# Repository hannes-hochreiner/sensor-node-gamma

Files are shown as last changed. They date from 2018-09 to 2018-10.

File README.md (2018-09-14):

# Sensor Node Gamma

## Core parts

### MCU
  * manufacturer: STMicroelectronics
  * manufacturer id: STM32L021K4T6
  * digi-key id: [497-17903-ND](https://www.digikey.de/product-detail/de/stmicroelectronics/STM32L021K4T6/497-17903-ND)
  * [datasheet](http://www.st.com/content/ccc/resource/technical/document/datasheet/86/a6/5f/95/33/50/4e/d6/DM00206858.pdf/files/DM00206858.pdf/jcr:content/translations/en.DM0020685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)
  * sleep current: 0.54 µA
  * price: 1.87 EUR

### transmitter
  * manufacturer: Silicon Labs
  * manufacturer id: SI4012-C1001GTR
  * digi-key id: [336-4153-1-ND](https://www.digikey.de/product-detail/de/silicon-labs/SI4012-C1001GTR/336-4153-1-ND/7650432)
  * [datasheet](http://www.silabs.com/documents/public/data-sheets/Si4012.pdf)
  * sleep current: 0.01 µA
  * price: 0.89 EUR

### sensor
  * manufacturer: Sensirion AG
  * manufacturer id: SHTC3
  * digi-key id: [1649-1105-1-ND](https://www.digikey.de/product-detail/de/sensirion-ag/SHTC3/1649-1105-1-ND/9477852)
  * [datasheet](https://media.digikey.com/pdf/Data%20Sheets/Sensirion%20PDFs/SHTC3_Prelim.pdf)
  * sleep current: 0.3 µA
  * price: 3.67 EUR

### antenna
  * manufacturer: Linx Technologies Inc.
  * manufacturer id: ANT-433-SP
  * digi-key id: [ANT-433-SP-ND](https://www.digikey.de/product-detail/de/linx-technologies-inc/ANT-433-SP/ANT-433-SP-ND/1679578)
  * [datasheet](https://linxtechnologies.com/wp/wp-content/uploads/ant-433-sp.pdf)
  * price: 2.07 EUR

## Power consumption

### Sleep

about 0.85 µA

CR2032: about 230 mAh

about 30 y of sleep

## Price

  * PCB: 7.50 EUR

price of the main components: 16 EUR

## Effort
  * system design: 1.5 h
  * circuit design: 2.5 h
  * pcb layout: 5.25 h
  * checks: 1.25 h

## TODOs
  * check all custom components and footprints

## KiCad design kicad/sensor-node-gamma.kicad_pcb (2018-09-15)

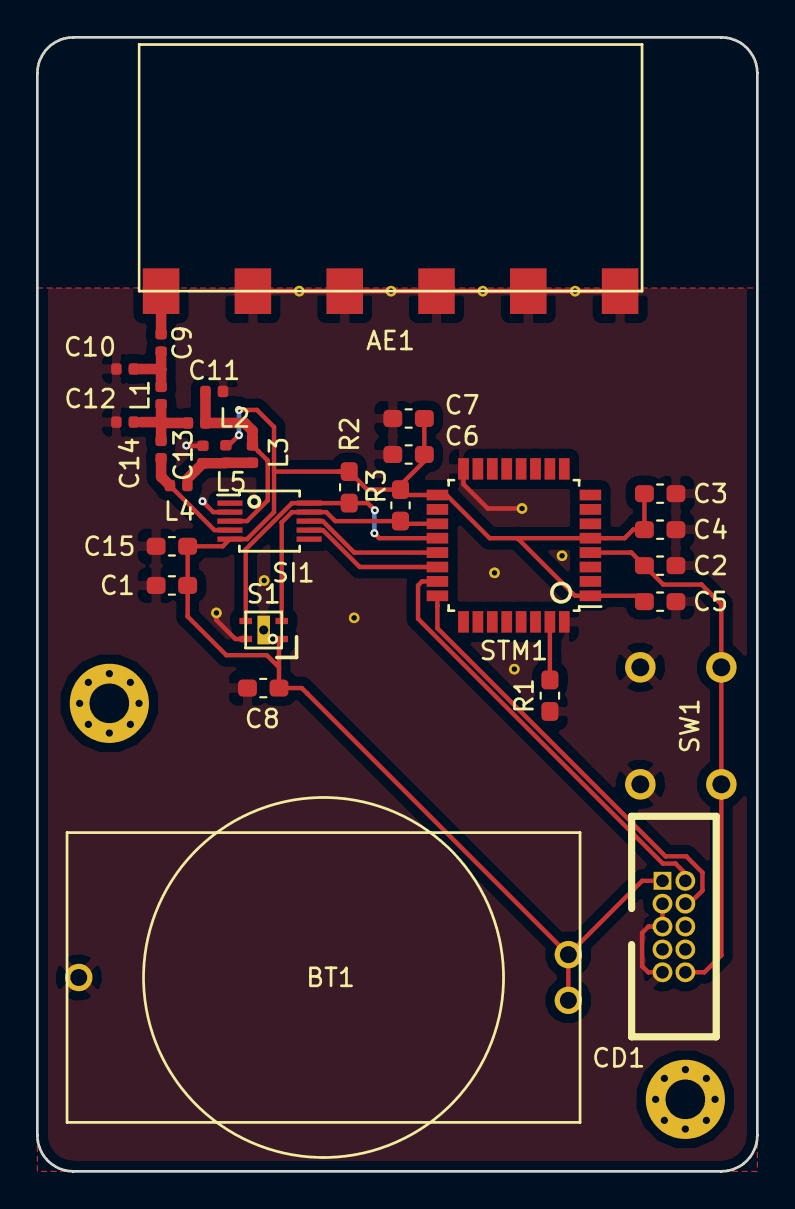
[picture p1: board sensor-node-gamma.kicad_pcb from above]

Board: 2 copper layers, 40.0 x 63.0 mm, 41 parts (0 on the bottom side), 16 nets.

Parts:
AE1: Antenna_Chip; ANT-433-SP
BT1: Custom_Battery; HU2032-LF
C1, C3: 1µF; C_0603_1608Metric_Pad1.05x0.95mm_HandSolder
C2, C4, C5, C6, C8, C15: 0.1µF; C_0603_1608Metric_Pad1.05x0.95mm_HandSolder
C7: 10µF; C_0603_1608Metric_Pad1.05x0.95mm_HandSolder
C9: 270pF; C_0402_1005Metric
C10, C12: 6.8pF; C_0402_1005Metric
C11: 4.3pF; C_0402_1005Metric
C13: 2.7pF; C_0402_1005Metric
C14: 1.8pF; C_0402_1005Metric
CD1: CORTEX-DEBUG
L1: 18nH; L_0402_1005Metric
L2: 56nH; L_0402_1005Metric
L3, L4: 16nH; L_0402_1005Metric
L5: 220nH; L_0402_1005Metric
R1, R2, R3: 10k; R_0603_1608Metric_Pad1.05x0.95mm_HandSolder
Ref**: Val**; STICH
Ref**#2, Ref**#3, Ref**#4, Ref**#5, Ref**#6, Ref**#7, Ref**#8, Ref**#9, Ref**#10, Ref**#11: Val**; STICH
S1: SHTC3
SI1: SI4012; MSOP-10_3x3mm_P0.5mm
STM1: STM32L021K4T6; LQFP-32_7x7mm_P0.8mm
SW1: SW_Push; switch

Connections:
/3V3: BT1.1, C1.2, C3.1, C4.1, C5.2, C6.1, C7.1, C8.1, C15.2, CD1.1, L5.1, R2.1, R3.2, S1.1, SI1.5, STM1.1, STM1.5, STM1.17
/I2C_SCL: R3.1, S1.2, SI1.9, STM1.19
/I2C_SDA: R2.2, S1.3, SI1.10, STM1.20
/RFM_ENABLE: SI1.8, STM1.21
/SWD_CLK: CD1.4, STM1.24
/SWD_IO: CD1.2, STM1.23
/~RFM_IRQ: SI1.7, STM1.22
/~SWD_RST: C2.1, CD1.10, STM1.4, SW1.2
GND: AE1.2, BT1.2, C1.1, C2.2, C3.2, C4.2, C5.1, C6.2, C7.2, C8.2, C10.1, C11.2, C12.1, C13.1, C15.1, CD1.3, CD1.5, CD1.9, R1.1, Ref**.1, Ref**#2.1, Ref**#3.1, Ref**#4.1, Ref**#5.1, Ref**#6.1, Ref**#7.1, Ref**#8.1, Ref**#9.1, Ref**#10.1, Ref**#11.1, S1.4, SI1.2, STM1.16, STM1.32, SW1.1
unnamed: AE1.1, C9.1
unnamed: C9.2, C10.2, L1.2
unnamed: C11.1, L2.1, L3.1, SI1.3
unnamed: C12.2, C14.2, L1.1, L2.2
unnamed: C13.2, L3.2, L4.1, L5.2
unnamed: C14.1, L4.2, SI1.4
unnamed: R1.2, STM1.31

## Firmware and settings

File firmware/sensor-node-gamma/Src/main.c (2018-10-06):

/**
  ******************************************************************************
  * @file           : main.c
  * @brief          : Main program body
  ******************************************************************************
  ** This notice applies to any and all portions of this file
  * that are not between comment pairs USER CODE BEGIN and
  * USER CODE END. Other portions of this file, whether 
  * inserted by the user or by software development tools
  * are owned by their respective copyright owners.
  *
  * COPYRIGHT(c) 2018 STMicroelectronics
  *
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
  ******************************************************************************
  */
/* Includes ------------------------------------------------------------------*/
#include "main.h"
#include "stm32l0xx_hal.h"
#include "aes.h"
#include "crc.h"
#include "i2c.h"
#include "gpio.h"


/* USER CODE BEGIN PV */

/* USER CODE END PV */

void SystemClock_Config(void);

/* USER CODE BEGIN PFP */

/* USER CODE END PFP */

/**
  * @brief  The application entry point.
  *
  * @retval None
  */
int main(void)
{
  /* MCU Configuration----------------------------------------------------------*/

  /* Reset of all peripherals, Initializes the Flash interface and the Systick. */
  HAL_Init();

  /* Configure the system clock */
  SystemClock_Config();

  /* Initialize all configured peripherals */
  MX_GPIO_Init();
  MX_AES_Init();
  MX_I2C1_Init();
  MX_CRC_Init();
  /* USER CODE BEGIN 2 */
  HAL_I2C_Init(&hi2c1);
  /* USER CODE END 2 */

  /* Infinite loop */
  /* USER CODE BEGIN WHILE */
  while (1)
  {
    // LL_GPIO_ResetOutputPin(RFM_ENABLE_GPIO_Port, RFM_ENABLE_Pin);
    LL_GPIO_SetOutputPin(RFM_ENABLE_GPIO_Port, RFM_ENABLE_Pin);

    volatile HAL_StatusTypeDef status;
    status = HAL_I2C_IsDeviceReady(&hi2c1, 0xE0, 10, 1000);
    // status = HAL_SMBUS_IsDeviceReady(&hsmbus1, 0xE0, 10, 1000);

    // reset
    // uint8_t comReset[] = {0x06};
    // status = HAL_I2C_Master_Transmit(&hi2c1, 0x00, comReset, 1, 1000);

    // if (status != HAL_OK) {
    //   volatile uint32_t errorCode = HAL_I2C_GetError(&hi2c1);
    //   volatile int tmp = 5;
    // }
    // HAL_Delay(1);

    // uint8_t comSleep[] = {0xB0, 0x98};
    // status = HAL_I2C_Master_Transmit(&hi2c1, 0xE0, comSleep, 2, 1000);
    // HAL_Delay(1);

    uint8_t comWake[] = {0x35, 0x17};
    status = HAL_I2C_Master_Transmit(&hi2c1, 0xE0, comWake, 2, 1000);
    // HAL_Delay(1);
    LL_mDelay(1);

    uint8_t comMeas[] = {0x7C, 0xA2};
    status = HAL_I2C_Master_Transmit(&hi2c1, 0xE0, comMeas, 2, 1000);
    
    uint8_t values[6];
    status = HAL_I2C_Master_Receive(&hi2c1, 0xE0, values, 6, 1000);

    uint8_t comSleep[] = {0xB0, 0x98};
    status = HAL_I2C_Master_Transmit(&hi2c1, 0x70, comSleep, 2, 1000);

    volatile uint16_t valueTemp = ((uint16_t)values[0] << 8) + (uint16_t)values[1];
    volatile uint16_t valueHum = ((uint16_t)values[3] << 8) + (uint16_t)values[4];

    CRC_Config_Sensor();

    volatile uint32_t crcTempCalc = HAL_CRC_Calculate(&hcrc, (uint32_t*)&values[0], 2);
    volatile uint32_t crcTempTrans = (uint32_t)values[2];

    volatile uint32_t crcHumCalc = HAL_CRC_Calculate(&hcrc, (uint32_t*)&values[3], 2);
    volatile uint32_t crcHumTrans = (uint32_t)values[5];

    //
    // transmitter
    //
    LL_GPIO_ResetOutputPin(RFM_ENABLE_GPIO_Port, RFM_ENABLE_Pin);
    LL_mDelay(100);

    // properties to be set:
    uint8_t transRes;
    // CHIP_CONFIG (0x10): 0x00
    uint8_t comChipConfig[] = {0x11, 0x10, 0x00};
    TransmitterCommand(comChipConfig, 3, &transRes, 1);
    if (transRes != 0x80) { Error_Handler(); }
    // PA_CONFIG (0x60): 0x00, 0x4D, 0x00, 0x19, 0x7D, 0xF3 => 9 dBm
    // PA_CONFIG (0x60): 0x01, 0x47, 0x00, 0x19, 0x7D, 0xF3 => 10 dBm
    uint8_t comPaConfig[] = {0x11, 0x60, 0x01, 0x47, 0x00, 0x19, 0x7D, 0xF3};
    TransmitterCommand(comPaConfig, 8, &transRes, 1);
    if (transRes != 0x80) { Error_Handler(); }
    // TX_FREQ (0x40): 0x19, 0xDF, 0x13, 0xD0 => 434.050 MHz
    uint8_t comTxFreq[] = {0x11, 0x40, 0x19, 0xDF, 0x13, 0xD0};
    TransmitterCommand(comTxFreq, 6, &transRes, 1);
    if (transRes != 0x80) { Error_Handler(); }
    // MODULATION_FSKDEV (0x20): 0x01, 0x4C => FSK, 50 kHz
    uint8_t comModulationFskdev[] = {0x11, 0x20, 0x01, 0x4C};
    TransmitterCommand(comModulationFskdev, 4, &transRes, 1);
    if (transRes != 0x80) { Error_Handler(); }
    // BITRATE_CONFIG (0x31): 0x00, 0x30, 0x04 => 4.8 kb/s
    uint8_t comBitrateConfig[] = {0x11, 0x31, 0x00, 0x30, 0x04};
    TransmitterCommand(comBitrateConfig, 5, &transRes, 1);
    if (transRes != 0x80) { Error_Handler(); }
    // OPTIONAL: CHANGE_STATE (0x60): 0x00, 0x02 => idle, tune
    uint8_t comChangeState[] = {0x60, 0x00, 0x02};
    TransmitterCommand(comChangeState, 3, &transRes, 1);
    if (transRes != 0x80) { Error_Handler(); }

    // set fifo
    uint8_t preambleLength = 10;
    uint8_t preambleCharacter = 0xAA;
    uint8_t messageData[] = {0x48, 0x45, 0x4C, 0x4C, 0x4F};
    uint8_t messageLength = 5;
    uint8_t comSetFifo[1 + preambleLength + 1 + messageLength + 2];
    
    comSetFifo[0] = 0x66;

    for (uint8_t cntr = 0; cntr < preambleLength; cntr++) {
      comSetFifo[cntr + 1] = preambleCharacter;
    }

    comSetFifo[1 + preambleLength] = messageLength;

    for (uint8_t cntr = 0; cntr < messageLength; cntr++) {
      comSetFifo[2 + preambleLength + cntr] = messageData[cntr];
    }

    // add crc calculation
    CRC_Config_Transmitter();
    uint32_t crcTrans = HAL_CRC_Calculate(&hcrc, (uint32_t*)&comSetFifo[7], 6);

    comSetFifo[2 + preambleLength + messageLength] = (uint8_t)(crcTrans >> 8);
    comSetFifo[2 + preambleLength + messageLength + 1] = (uint8_t)crcTrans;

    TransmitterCommand(comSetFifo, 4 + preambleLength + messageLength, &transRes, 1);
    if (transRes != 0x80) { Error_Handler(); }

    uint8_t comTxStart[] = {0x62, 0x00, 0x10, 0x00, 0x00, 0x00};
    uint8_t dataTxStart[2];
    TransmitterCommand(comTxStart, 6, dataTxStart, 2);
    if (dataTxStart[0] != 0x80) { Error_Handler(); }

    uint8_t comGetIntStatus[] = {0x64};
    uint8_t dataGetIntStatus[2];
    volatile uint8_t pkgSent = 0;

    while (pkgSent != 8) {
      LL_mDelay(30);
      dataGetIntStatus[1] = 0;
      TransmitterCommand(comGetIntStatus, 1, dataGetIntStatus, 2);
      if (dataGetIntStatus[0] != 0x80) { Error_Handler(); }
      pkgSent = dataGetIntStatus[1] & 0x08;
    }

    LL_GPIO_ResetOutputPin(RFM_ENABLE_GPIO_Port, RFM_ENABLE_Pin);
    LL_mDelay(500);
  /* USER CODE END WHILE */

  /* USER CODE BEGIN 3 */

  }
  /* USER CODE END 3 */

}

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
/* USER CODE BEGIN 4 */
void CRC_Config_Sensor() {
  HAL_CRC_DeInit(&hcrc);
  hcrc.Init.DefaultPolynomialUse = DEFAULT_POLYNOMIAL_DISABLE;
  hcrc.Init.DefaultInitValueUse = DEFAULT_INIT_VALUE_DISABLE;
  hcrc.Init.GeneratingPolynomial = 0x31;
  hcrc.Init.CRCLength = CRC_POLYLENGTH_8B;
  hcrc.Init.InitValue = 0xFF;
  hcrc.InputDataFormat = CRC_INPUTDATA_FORMAT_BYTES;
  HAL_CRC_Init(&hcrc);
}

void CRC_Config_Transmitter() {
  HAL_CRC_DeInit(&hcrc);
  hcrc.Init.DefaultPolynomialUse = DEFAULT_POLYNOMIAL_DISABLE;
  hcrc.Init.DefaultInitValueUse = DEFAULT_INIT_VALUE_DISABLE;
  hcrc.Init.GeneratingPolynomial = 0x1D0F;
  hcrc.Init.CRCLength = CRC_POLYLENGTH_16B;
  hcrc.Init.InitValue = 0x1D0F;
  hcrc.InputDataFormat = CRC_INPUTDATA_FORMAT_BYTES;
  HAL_CRC_Init(&hcrc);
}

void TransmitterCommand(uint8_t* comBuf, uint8_t comLen, uint8_t* resBuf, uint8_t resLen) {
  volatile HAL_StatusTypeDef status = HAL_OK;

  status = HAL_I2C_Master_Transmit(&hi2c1, 0xE0, comBuf, comLen, 1000);

  if (status != HAL_OK) {
    volatile uint32_t error = HAL_I2C_GetError(&hi2c1);
    Error_Handler();
  }

  status = HAL_I2C_Master_Receive(&hi2c1, 0xE0, resBuf, resLen, 1000);

  for (uint8_t cntr = 0; cntr < 15 && status != HAL_OK; cntr++) {
    LL_mDelay(10);
    status = HAL_I2C_Master_Receive(&hi2c1, 0xE0, resBuf, resLen, 1000);
  }

  if (status != HAL_OK) {
    volatile uint32_t error = HAL_I2C_GetError(&hi2c1);
    Error_Handler();
  }
}
/* USER CODE END 4 */
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


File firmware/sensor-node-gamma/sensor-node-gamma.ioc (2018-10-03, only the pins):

Mcu.UserName=STM32L021K4Tx
PA10.Signal=I2C1_SDA
PA11.GPIO_Label=RFM_ENABLE
PA11.Signal=GPIO_Output
PA12.GPIO_Label=RFM_IRQ
PA12.Signal=GPIO_Input
PA13.Signal=SYS_SWDIO
PA14.Signal=SYS_SWCLK
PA9.Signal=I2C1_SCL

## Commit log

2018-09-02 initial design commit
    [sensor-node-gamma.kicad_pcb, sensor-node-gamma.sch]
2018-09-02 changes antenna footprint
    [sensor-node-gamma.kicad_pcb]
2018-09-04 updated to kicad 5
    [sensor-node-gamma.kicad_pcb, sensor-node-gamma.sch]
2018-09-06 re-routed pcb
    [sensor-node-gamma.kicad_pcb]
2018-09-07 re-rerouted pcb
    [sensor-node-gamma.kicad_pcb]
2018-09-10 added cap for sensor
    [sensor-node-gamma.kicad_pcb, sensor-node-gamma.sch]
2018-09-12 updated design rules and ran check
    [sensor-node-gamma.kicad_pcb]
2018-09-14 switched to more easily available parts
2018-09-15 exchanged radio and sensor in schematic
    [sensor-node-gamma.sch]
2018-09-15 added footprints
    [sensor-node-gamma.sch]
2018-09-15 added new antenna
    [sensor-node-gamma.sch]
2018-09-15 update PCB
    [sensor-node-gamma.kicad_pcb, sensor-node-gamma.sch]
2018-09-15 updated PCB
    [sensor-node-gamma.kicad_pcb]
2018-09-15 added better pin 1 marks
    [sensor-node-gamma.kicad_pcb]
2018-10-02 sensor working
    [oo.cfg]

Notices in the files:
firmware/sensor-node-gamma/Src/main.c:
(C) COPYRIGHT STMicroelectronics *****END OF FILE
